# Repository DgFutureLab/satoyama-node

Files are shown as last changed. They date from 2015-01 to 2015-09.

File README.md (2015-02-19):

satoyama-node
=============

Satoyama Sensor Network node stack. This stack is designed to connect chibis and sabotens to <a href="https://github.com/DgFutureLab/satoyama-api">Satoyama API</a>. Created by <a href="http://fljapan.com/">Future Lab</a> based on <a href="http://www.freaklabsstore.com">Freaklabs open hardware</a>.

# Prerequisites

## Hardware
(List of provided parts: board, sensors, batteries, etc.)

(NOTE: Add mark on saboten board to connect the FTDI Breakout board in the right direction!!)

## Software
1. Arduino IDE 1.0.6 (Does not work with Arduino 1.5.8 BETA). Get it <a href="http://www.arduino.cc/">here</a>
2. git

# Installation
Follow these steps to set up a Satoyama sensor node!
## Get the code
1. Download this repository: $ git clone https://github.com/DgFutureLab/satoyama-node.git
2. Go into the new directory: $ cd satoyama-node
3. Download all the libraries: $ git pull && git submodule init && git submodule update && git submodule status

## Prepare Arduino libraries

Import the required libraries into your Arduino IDE:  

1. satoyama-libs/SatoyamaChibiLib 
2. satoyama-libs/SdFat 
3. satoyama-libs/chibiArduino-master
4. satoyama-libs/PCF2127
5. satoyama-libs/Humidity_Temperature_Sensor
6. satoyama-libs/NewPing

If you use the standard Arduino GUI, go to Sketch → Import Library → Add Library and select each library name folder.

For the Saboten board: 

1. Copy the folder 'mighty-1284p-freaklabs' inside satoyama-libs to a folder called 'hardware' off your sketches directory, e.g. /Users/maniacbug/Source/Arduino/hardware/mighty-1284p
In a Mac environment: Arduino.app/contents/resources/Java/hardware/
2. Restart the IDE
3. Select Tools > Board > Freaklabs Saboten...

## Prepare the hardware

1. Attach a sonnar, a temperature sensor and a humidity sensor. The pin numbers are specified in <a href="https://github.com/DgFutureLab/satoyama-node/blob/master/SatoyamaChibiLib/config.h">this file</a> (6 for sonar, 0 for temp/humidity)
2. Connect the board to the computer
 
-In case of the Saboten:
Check that the FTDI Breakout board switch is on 5V

3. For OSX users, download the FTDI drivers from http://www.ftdichip.com/Drivers/VCP.htm

4. Open test_saboten/test_saboten.ino (for saboten)
4. Open File>Examples>Chibiarduino-master>4.cmdline (for Chibi)
5. Select your board on the dropdown menu Tool>Board>(FreakLabs Saboten for the saboten) or (Arduino Pro or ProMini (3.3V, 8MHz) w/ATmega328)
6. Upload it to the board
7. Open Arduino IDE's Serial Monitor
8. Set the communication to Carriage return and 57600 baud
9. Set the short address of this collector node by hand writing   *setsaddr* \<address\>  in the serial monitor command prompt. The address should be in HEXADECIMAL. (The address is currently (as of Jan, 2015) set via the script in satoyama-konohana) 
9. Upload collector/collector.ino into your Saboten board. (Include all the necessary libs from third-party-libs folder)

## Setup build system with CMake
Before we wrote the sketches using the Arduino GUI, but now we use standard CMake to generate make files.

1. Install CMake (e.g. brew install cmake on OSX)
2. Change directory into the folder containing the source code that you want to run on the board.
3. mkdir build (all the build files will be stored in this directory)
4. Navigate to build directory: cd build 
5. compile source code and upload to the device: cmake .. -Wno-dev && make && make upload (make sure that the build directory is empty, as CMake will complain otherwise)
6. Use screen to monitor output from the serial device (e.g. tty.usbserial-A501K9HW): /dev/tty.usbserial-A501K9HW 57600,sc8

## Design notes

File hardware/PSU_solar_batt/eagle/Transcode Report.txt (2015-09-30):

   ---- Transcoding 'E:\Jobs\Temp files\sonar\Voltage Regulator\Regulator\Regulator.GBL' ----   Mon Aug 31 23:26:08 2015

D10   --> D100
D11   --> D101
-----------------------------------------------------------------

   ---- Transcoding 'E:\Jobs\Temp files\sonar\Voltage Regulator\Regulator\Regulator.GBS' ----   Mon Aug 31 23:26:08 2015

D11   --> D102
-----------------------------------------------------------------

   ---- Transcoding 'E:\Jobs\Temp files\sonar\Voltage Regulator\Regulator\Regulator.GTL' ----   Mon Aug 31 23:26:08 2015

D10   --> D103
D11   --> D104
D12   --> D105
D13   --> D106
D14   --> D107
D15   --> D108
D16   --> D109
-----------------------------------------------------------------

   ---- Transcoding 'E:\Jobs\Temp files\sonar\Voltage Regulator\Regulator\Regulator.GTO' ----   Mon Aug 31 23:26:08 2015

D10   --> D110
D11   --> D111
D12   --> D112
D13   --> D113
D14   --> D114
-----------------------------------------------------------------

   ---- Transcoding 'E:\Jobs\Temp files\sonar\Regulator\MCP Regulator\Regulator\Regulator.GBS' ----   Sat Sep 19 06:32:56 2015

D10   --> D100
D11   --> D101
D12   --> D102
D13   --> D103
-----------------------------------------------------------------

   ---- Transcoding 'E:\Jobs\Temp files\sonar\Regulator\MCP Regulator\Regulator\Regulator.GTL' ----   Sat Sep 19 06:32:56 2015

D10   --> D104
D11   --> D105
D12   --> D106
D13   --> D107
D14   --> D108
D15   --> D109
-----------------------------------------------------------------

   ---- Transcoding 'E:\Jobs\Temp files\sonar\Regulator\MCP Regulator\Regulator\Regulator.GTO' ----   Sat Sep 19 06:32:56 2015

D10   --> D110
D11   --> D111
D12   --> D112
D13   --> D113
D14   --> D114
D15   --> D115
D16   --> D116
-----------------------------------------------------------------

   ---- Transcoding 'E:\Jobs\Temp files\sonar\Regulator\MCP Regulator\Regulator\Regulator.GTS' ----   Sat Sep 19 06:32:56 2015

D10   --> D117
D11   --> D118
D12   --> D119
D13   --> D120
D14   --> D121
D15   --> D122
D16   --> D123
D17   --> D124
D18   --> D125
-----------------------------------------------------------------

   ---- Transcoding 'E:\Jobs\Temp files\sonar\Regulator\MCP Regulator\BackUp\Regulator\Regulator.GBS' ----   Sat Sep 26 23:08:06 2015

D10   --> D100
D11   --> D101
D13   --> D102
D14   --> D103
D15   --> D104
D16   --> D105
D17   --> D106
D18   --> D107
D19   --> D108
D20   --> D109
-----------------------------------------------------------------

   ---- Transcoding 'E:\Jobs\Temp files\sonar\Regulator\MCP Regulator\BackUp\Regulator\Regulator.GTL' ----   Sat Sep 26 23:08:06 2015

D10   --> D110
D11   --> D111
D12   --> D112
D13   --> D113
D14   --> D114
D15   --> D115
D16   --> D116
D17   --> D117
D18   --> D118
D19   --> D119
D20   --> D120
D21   --> D121
D22   --> D122
D23   --> D123
D24   --> D124
-----------------------------------------------------------------

   ---- Transcoding 'E:\Jobs\Temp files\sonar\Regulator\MCP Regulator\BackUp\Regulator\Regulator.GTO' ----   Sat Sep 26 23:08:06 2015

D10   --> D125
D11   --> D126
D12   --> D127
D13   --> D128
D14   --> D129
D15   --> D130
D17   --> D131
D18   --> D132
D20   --> D133
-----------------------------------------------------------------

   ---- Transcoding 'E:\Jobs\Temp files\sonar\Regulator\MCP Regulator\BackUp\Regulator\Regulator.GTS' ----   Sat Sep 26 23:08:06 2015

D10   --> D134
D11   --> D135
D12   --> D136
D13   --> D137
D14   --> D138
D15   --> D139
D16   --> D140
D17   --> D141
D18   --> D142
D19   --> D143
D20   --> D144
D21   --> D145
D22   --> D146
D23   --> D147
D24   --> D148
D25   --> D149
D26   --> D150
D27   --> D151
D28   --> D152
-----------------------------------------------------------------

   ---- Transcoding 'E:\Jobs\Temp files\sonar\Regulator\MCP Regulator\BackUp\Regulator\Regulator.GBS' ----   Sat Sep 26 23:10:48 2015

D10   --> D153
D11   --> D154
D13   --> D155
D14   --> D156
D15   --> D157
D16   --> D158
D17   --> D159
D18   --> D160
D19   --> D161
D20   --> D162
-----------------------------------------------------------------

   ---- Transcoding 'E:\Jobs\Temp files\sonar\Regulator\MCP Regulator\BackUp\Regulator\Regulator.GTL' ----   Sat Sep 26 23:10:48 2015

D10   --> D163
D11   --> D164
D12   --> D165
D13   --> D166
D14   --> D167
D15   --> D168
D16   --> D169
D17   --> D170
D18   --> D171
D19   --> D172
D20   --> D173
D21   --> D174
D22   --> D175
D23   --> D176
D24   --> D177
-----------------------------------------------------------------

   ---- Transcoding 'E:\Jobs\Temp files\sonar\Regulator\MCP Regulator\BackUp\Regulator\Regulator.GTO' ----   Sat Sep 26 23:10:48 2015

D10   --> D178
D11   --> D179
D12   --> D180
D13   --> D181
D14   --> D182
D15   --> D183
D17   --> D184
D18   --> D185
D20   --> D186
-----------------------------------------------------------------

   ---- Transcoding 'E:\Jobs\Temp files\sonar\Regulator\MCP Regulator\BackUp\Regulator\Regulator.GTS' ----   Sat Sep 26 23:10:48 2015

D10   --> D187
D11   --> D188
D12   --> D189
D13   --> D190
D14   --> D191
D15   --> D192
D16   --> D193
D17   --> D194
D18   --> D195
D19   --> D196
D20   --> D197
D21   --> D198
D22   --> D199
D23   --> D200
D24   --> D201
D25   --> D202
D26   --> D203
D27   --> D204
D28   --> D205
-----------------------------------------------------------------

   ---- Transcoding 'E:\Jobs\Temp files\sonar\Regulator\MCP Regulator\BackUp\Regulator\Regulator.GBS' ----   Sat Sep 26 23:12:03 2015

D10   --> D100
D11   --> D101
D13   --> D102
D14   --> D103
D15   --> D104
D16   --> D105
D17   --> D106
D18   --> D107
D19   --> D108
D20   --> D109
-----------------------------------------------------------------

   ---- Transcoding 'E:\Jobs\Temp files\sonar\Regulator\MCP Regulator\BackUp\Regulator\Regulator.GTL' ----   Sat Sep 26 23:12:03 2015

D10   --> D110
D11   --> D111
D12   --> D112
D13   --> D113
D14   --> D114
D15   --> D115
D16   --> D116
D17   --> D117
D18   --> D118
D19   --> D119
D20   --> D120
D21   --> D121
D22   --> D122
D23   --> D123
D24   --> D124
-----------------------------------------------------------------

   ---- Transcoding 'E:\Jobs\Temp files\sonar\Regulator\MCP Regulator\BackUp\Regulator\Regulator.GTO' ----   Sat Sep 26 23:12:03 2015

D10   --> D125
D11   --> D126
D12   --> D127
D13   --> D128
D14   --> D129
D15   --> D130
D17   --> D131
D18   --> D132
D20   --> D133
-----------------------------------------------------------------

   ---- Transcoding 'E:\Jobs\Temp files\sonar\Regulator\MCP Regulator\BackUp\Regulator\Regulator.GTS' ----   Sat Sep 26 23:12:03 2015

D10   --> D134
D11   --> D135
D12   --> D136
D13   --> D137
D14   --> D138
D15   --> D139
D16   --> D140
D17   --> D141
D18   --> D142
D19   --> D143
D20   --> D144
D21   --> D145
D22   --> D146
D23   --> D147
D24   --> D148
D25   --> D149
D26   --> D150
D27   --> D151
D28   --> D152
-----------------------------------------------------------------

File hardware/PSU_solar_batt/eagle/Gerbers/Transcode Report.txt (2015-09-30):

   ---- Transcoding 'E:\Jobs\Temp files\sonar\Regulator\MCP Regulator\Regulator\Gerbers\Regulator.GBS' ----   Mon Sep 21 23:30:57 2015

D10   --> D100
D11   --> D101
D13   --> D102
D14   --> D103
D15   --> D104
-----------------------------------------------------------------

   ---- Transcoding 'E:\Jobs\Temp files\sonar\Regulator\MCP Regulator\Regulator\Gerbers\Regulator.GTL' ----   Mon Sep 21 23:30:57 2015

D10   --> D105
D11   --> D106
D12   --> D107
D13   --> D108
D14   --> D109
D15   --> D110
D16   --> D111
D17   --> D112
D18   --> D113
-----------------------------------------------------------------

   ---- Transcoding 'E:\Jobs\Temp files\sonar\Regulator\MCP Regulator\Regulator\Gerbers\Regulator.GTO' ----   Mon Sep 21 23:30:57 2015

D10   --> D114
D11   --> D115
D12   --> D116
D13   --> D117
D14   --> D118
D15   --> D119
D16   --> D120
-----------------------------------------------------------------

   ---- Transcoding 'E:\Jobs\Temp files\sonar\Regulator\MCP Regulator\Regulator\Gerbers\Regulator.GTS' ----   Mon Sep 21 23:30:57 2015

D10   --> D121
D11   --> D122
D12   --> D123
D13   --> D124
D14   --> D125
D15   --> D126
D16   --> D127
D17   --> D128
D18   --> D129
D19   --> D130
D20   --> D131
-----------------------------------------------------------------

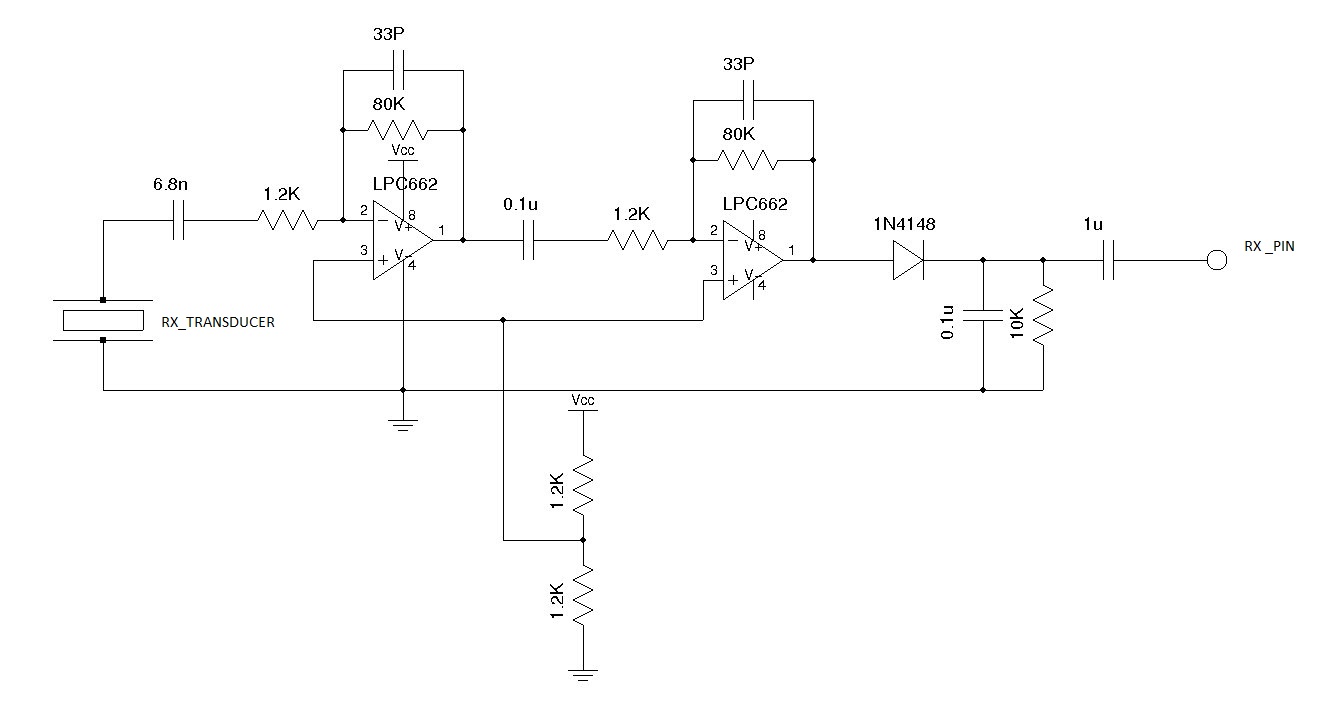
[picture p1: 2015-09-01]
hardware/range_finder/design2/hbridge/RX.jpg

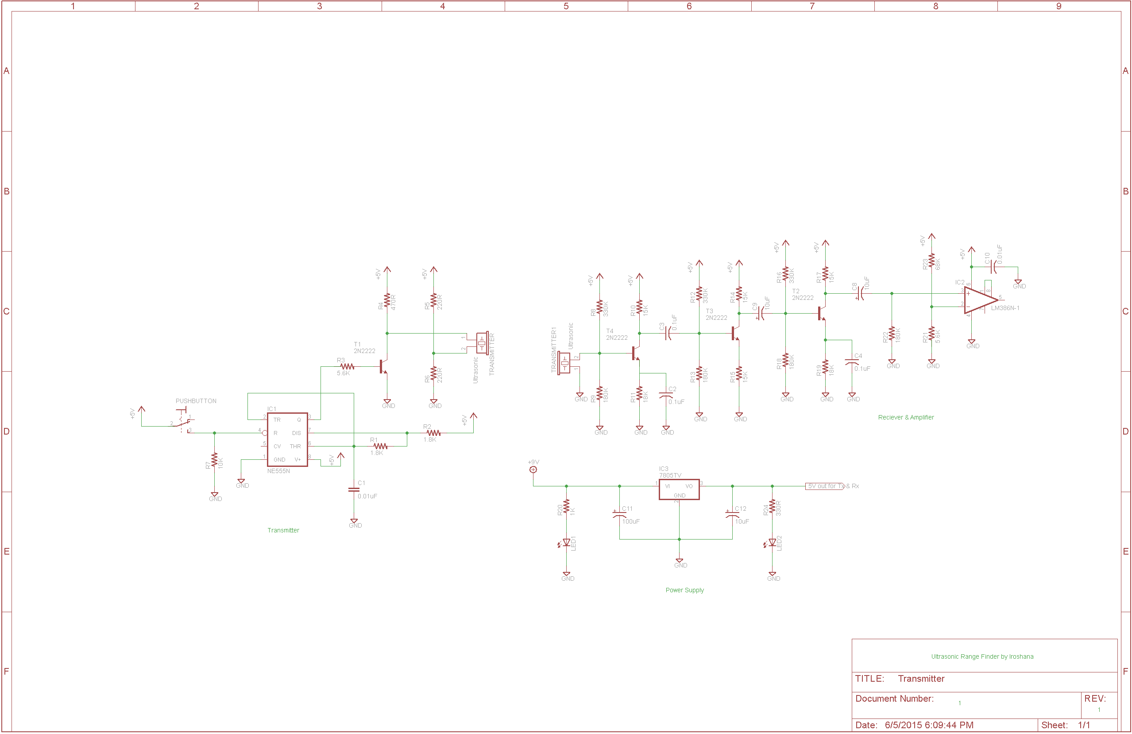
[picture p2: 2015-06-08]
hardware/range_finder/design1/Schematics/Schematics.png

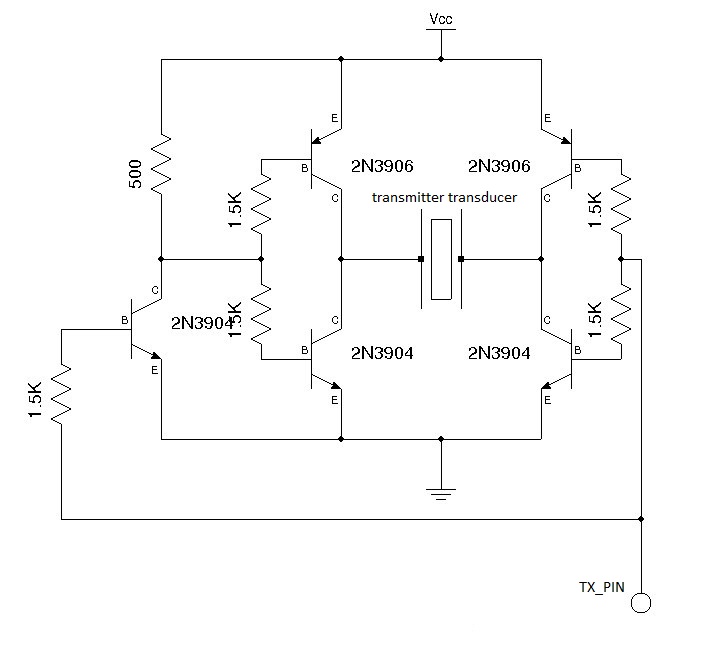
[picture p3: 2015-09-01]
hardware/range_finder/design2/hbridge/TX.jpg

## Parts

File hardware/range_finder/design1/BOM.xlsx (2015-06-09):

 | Bill Of Materials - Ultrasonic Range Finder
Part |  | Qty
Ics
555 |  | 1
LM386 |  | 1
Transistors
2N2222 |  | 4
Resistors(0.25W)
220ohm |  | 2
330ohm |  | 1
470ohm |  | 1
1K |  | 1
1.8K |  | 1
5.6K |  | 2
15K |  | 4
18K |  | 2
68K |  | 1
180K |  | 4
330K |  | 3
Capacitors
10uF(25V, Electrolytic) |  | 3
0.1uF(Ceramic) |  | 5
0.01uF (Ceramic) |  | 2
LM7805 |  | 1
Pin 8 IC Base |  | 2
LED Red |  | 1
LED Green |  | 1
1N4007 Diode |  | 1

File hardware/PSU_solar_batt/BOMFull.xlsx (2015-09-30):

Part |  | Qty | Schematic Ref. No: | Store Part No: | Manu: No: | Store
MCP1642B/D | REGULATOR IC | 1 | IC1 | 579-MCP1642D-18I/MS (http://www.mouser.com/ProductDetail/Microchip-Technology/MCP1642D-18I-MS/) | MCP1642D-18I/MS (http://www.mouser.com/ProductDetail/Microchip-Technology/MCP1642D-18I-MS/) | Mouser
MCP1642D-ADJ | REGULATOR IC | 1 | IC2 | MCP1642B-ADJI/MS-ND | MCP1642B-ADJI/MS | Digikey
10uF(16V) | CAPACITOR(ELECTROLYTIC) | 4 | C1-C4 | 565-4265-1-ND | EMLE160ADA100MD73G | Digikey
4.7uH | INDUCTOR | 2 | L1,L2 | 732-3333-1-ND (http://www.digikey.com/product-detail/en/74437324047/732-3333-1-ND/2791031) | 74437324047 (http://www.digikey.com/product-detail/en/74437324047/732-3333-1-ND/2791031) | Digikey
1MOHM | RESISTOR(0.25W) | 1 | R4 | 311-1.0MERCT-ND (http://www.digikey.com/product-detail/en/RC1206JR-071ML/311-1.0MERCT-ND/732134) | RC1206JR-071ML (http://www.digikey.com/product-detail/en/RC1206JR-071ML/311-1.0MERCT-ND/732134) | Digikey
820KOHM | RESISTOR(0.25W) | 1 | R6 | 311-820KFRCT-ND (http://www.digikey.com/product-detail/en/RC1206FR-07820KL/311-820KFRCT-ND/732081) | RC1206FR-07820KL (http://www.digikey.com/product-detail/en/RC1206FR-07820KL/311-820KFRCT-ND/732081) | Digikey
150KOHM | RESISTOR(0.25W) | 3 | R1-R3 | 311-150KERCT-ND (http://www.digikey.com/product-detail/en/RC1206JR-07150KL/311-150KERCT-ND/732171) | RC1206JR-07150KL (http://www.digikey.com/product-detail/en/RC1206JR-07150KL/311-150KERCT-ND/732171) | Digikey
2WAY DIP SWITCH |  | 1 | REGULATORS | CT2092MS-ND (http://www.digikey.com/product-detail/en/209-2MS/CT2092MS-ND/217658) | 209-2MS (http://www.digikey.com/product-detail/en/209-2MS/CT2092MS-ND/217658) | Digikey
3PIN MALE HEADER |  | 1 | SV1 | 3M9448-ND (http://www.digikey.com/product-detail/en/961103-6404-AR/3M9448-ND/2071489) | 961103-6404-AR (http://www.digikey.com/product-detail/en/961103-6404-AR/3M9448-ND/2071489) | Digikey
JST-XH |  | 1 | BATIN | A33893-ND (http://www.digikey.com/product-detail/en/5-103669-1/A33893-ND/1000909) | 5-103669-1 (http://www.digikey.com/product-detail/en/5-103669-1/A33893-ND/1000909) | Digikey
2PIN CONNECTOR |  | 3 | SOLARINPUT,3.3VOUT,5VOUT | ED1975-ND | EDZ500/2DS | Digikey

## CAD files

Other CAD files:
enclosure/protector.3dm

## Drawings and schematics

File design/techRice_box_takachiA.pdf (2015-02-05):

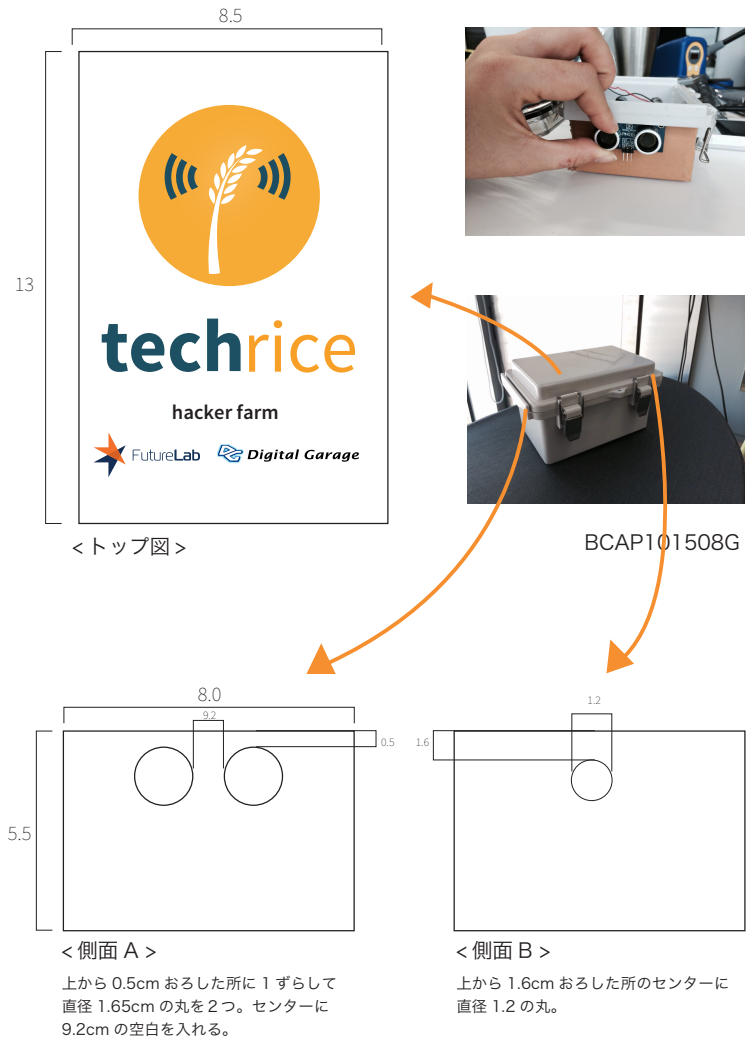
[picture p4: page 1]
上から 1.6cm おろした所のセンターに 直径 1.2 の丸。; hacker farm; rice; < トップ図 >; BCAP101508G

上から 0.5cm おろした所に 1 ずらして
直径 1.65cm の丸を２つ。センターに
9.2cm の空白を入れる。

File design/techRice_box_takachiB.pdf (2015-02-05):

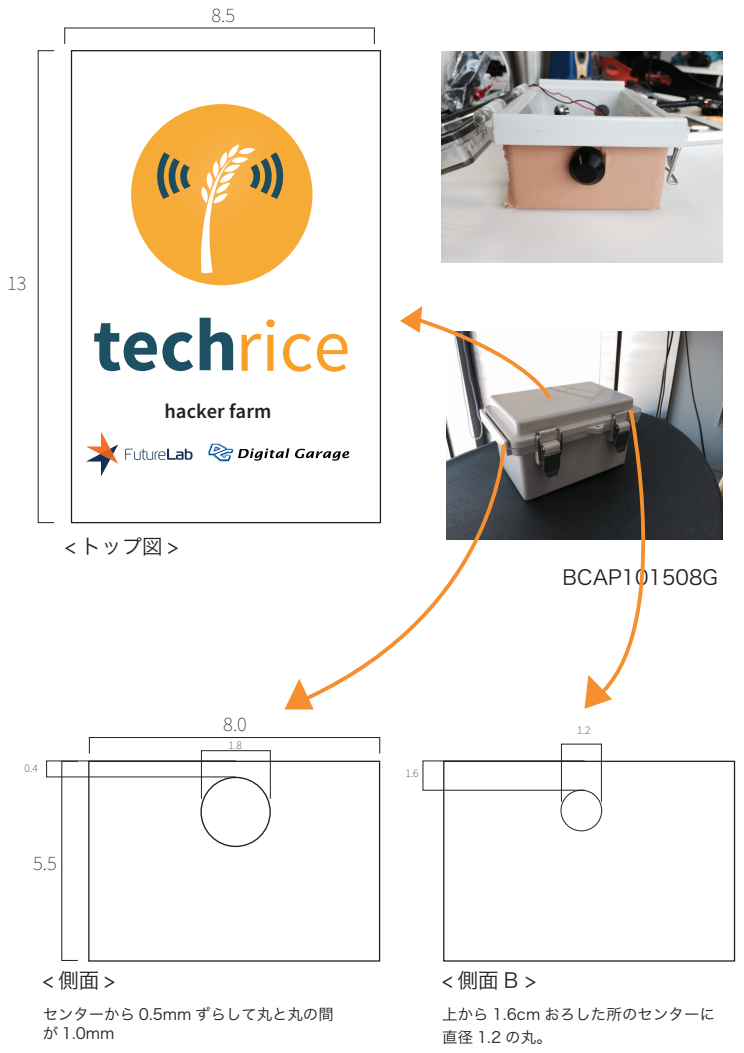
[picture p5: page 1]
BCAP101508G; 上から 1.6cm おろした所のセンターに 直径 1.2 の丸。; hacker farm; rice; < トップ図 >; センターから 0.5mm ずらして丸と丸の間 が 1.0mm

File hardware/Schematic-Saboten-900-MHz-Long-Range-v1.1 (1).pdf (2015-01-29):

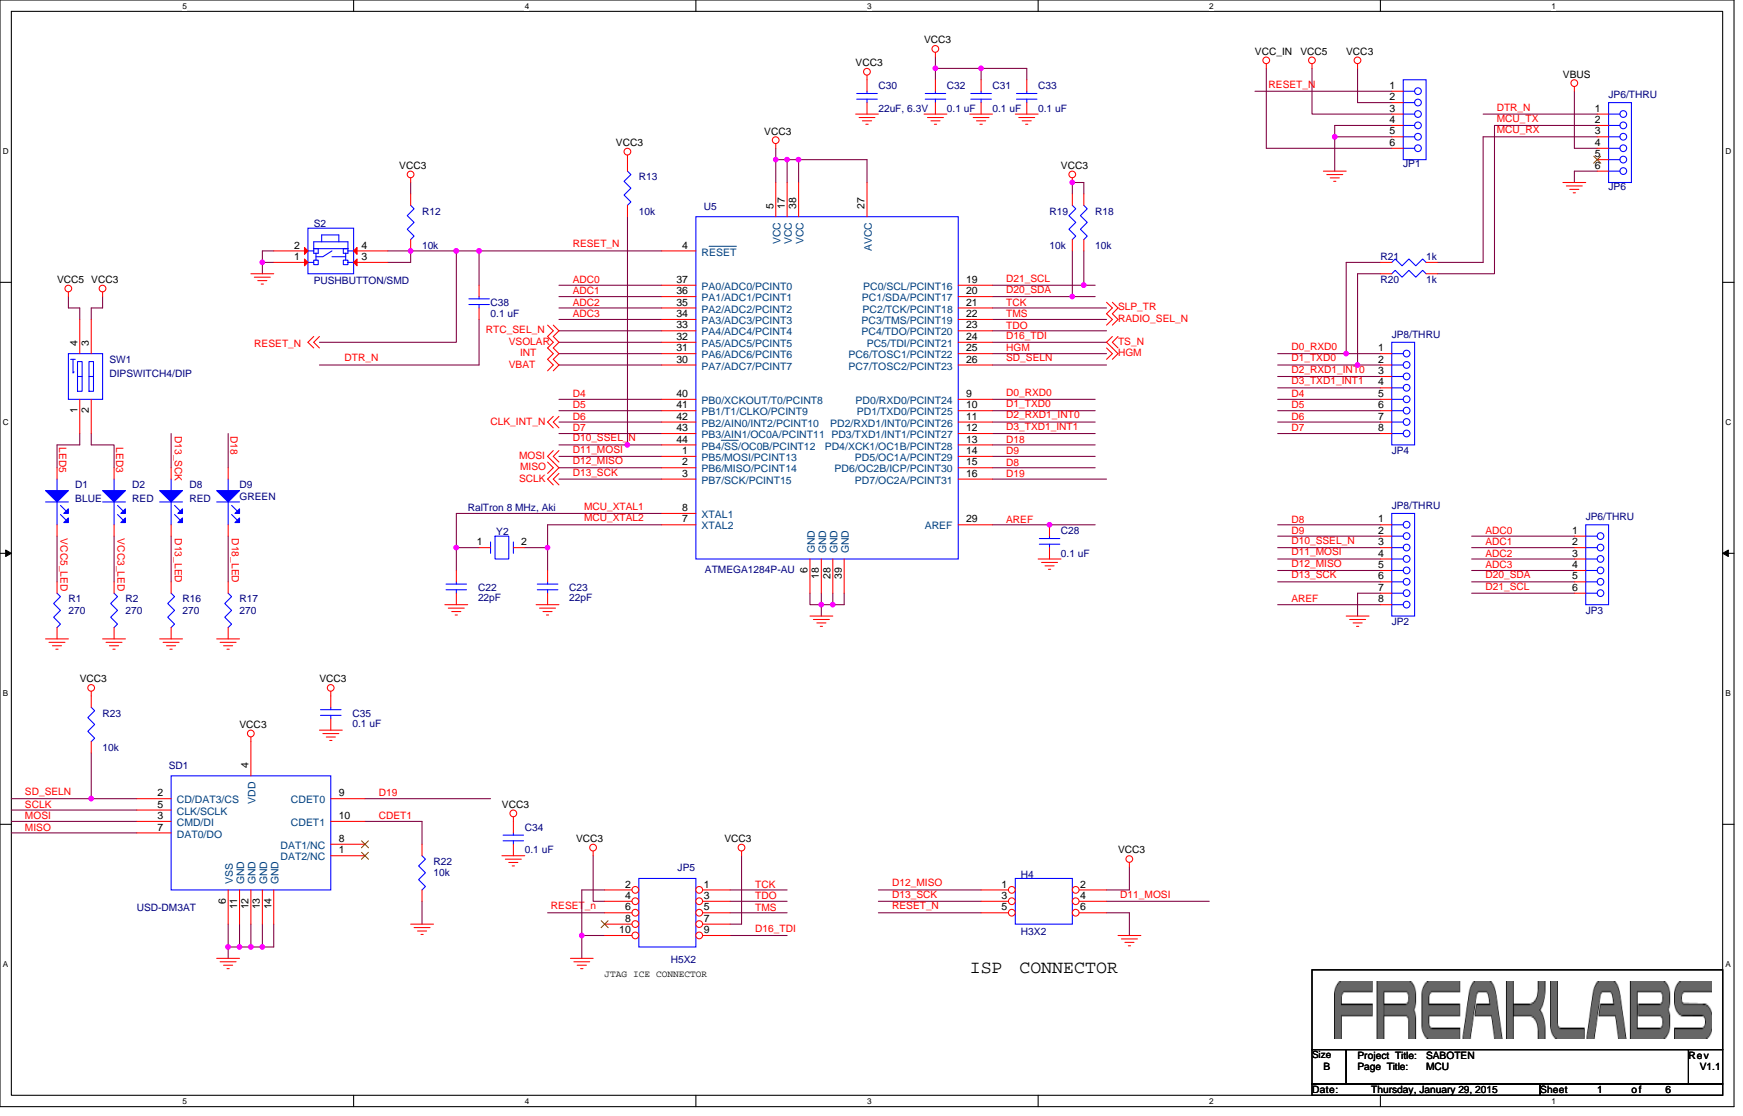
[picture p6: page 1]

Size Size Size B B B | Project Title: Project Title: Project Title: SABOTEN SABOTEN SABOTEN Page Title: Page Title: Page Title: MCU MCU MCU | Rev Rev Rev V1.1 V1.1 V1.1

Date: Date: Date: Thursday, January 29, 2015 Thursday, January 29, 2015 Thursday, January 29, 2015 | Sheet Sheet Sheet 1 1 1 of of of 6 6 6

D | D

H3

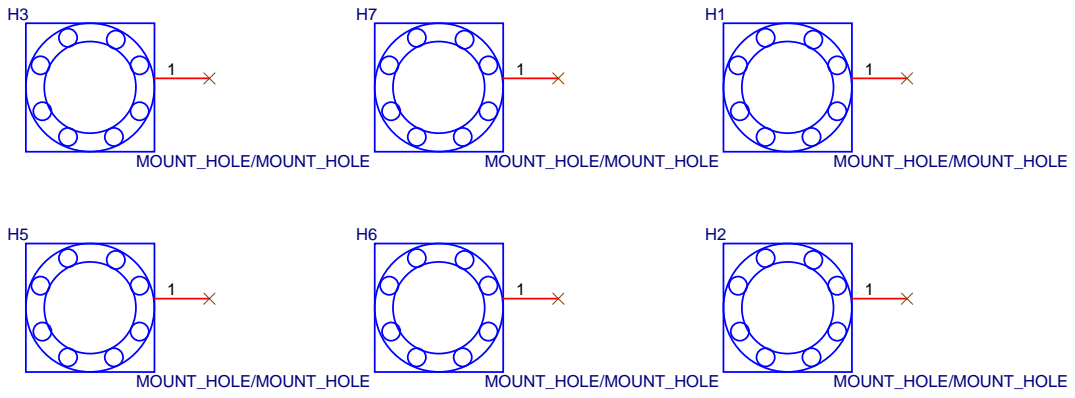
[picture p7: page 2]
MOUNT_HOLE/MOUNT_HOLE

Size Size Size A A A | Project Title: Project Title: Project Title: SABOTEN SABOTEN SABOTEN Page Title: Page Title: Page Title: MISC MISC MISC | Rev Rev Rev V1.1 V1.1 V1.1

Date: Date: Date: Thursday, January 29, 2015 Thursday, January 29, 2015 Thursday, January 29, 2015 | Sheet Sheet Sheet 2 2 2 of of of 6 6 6

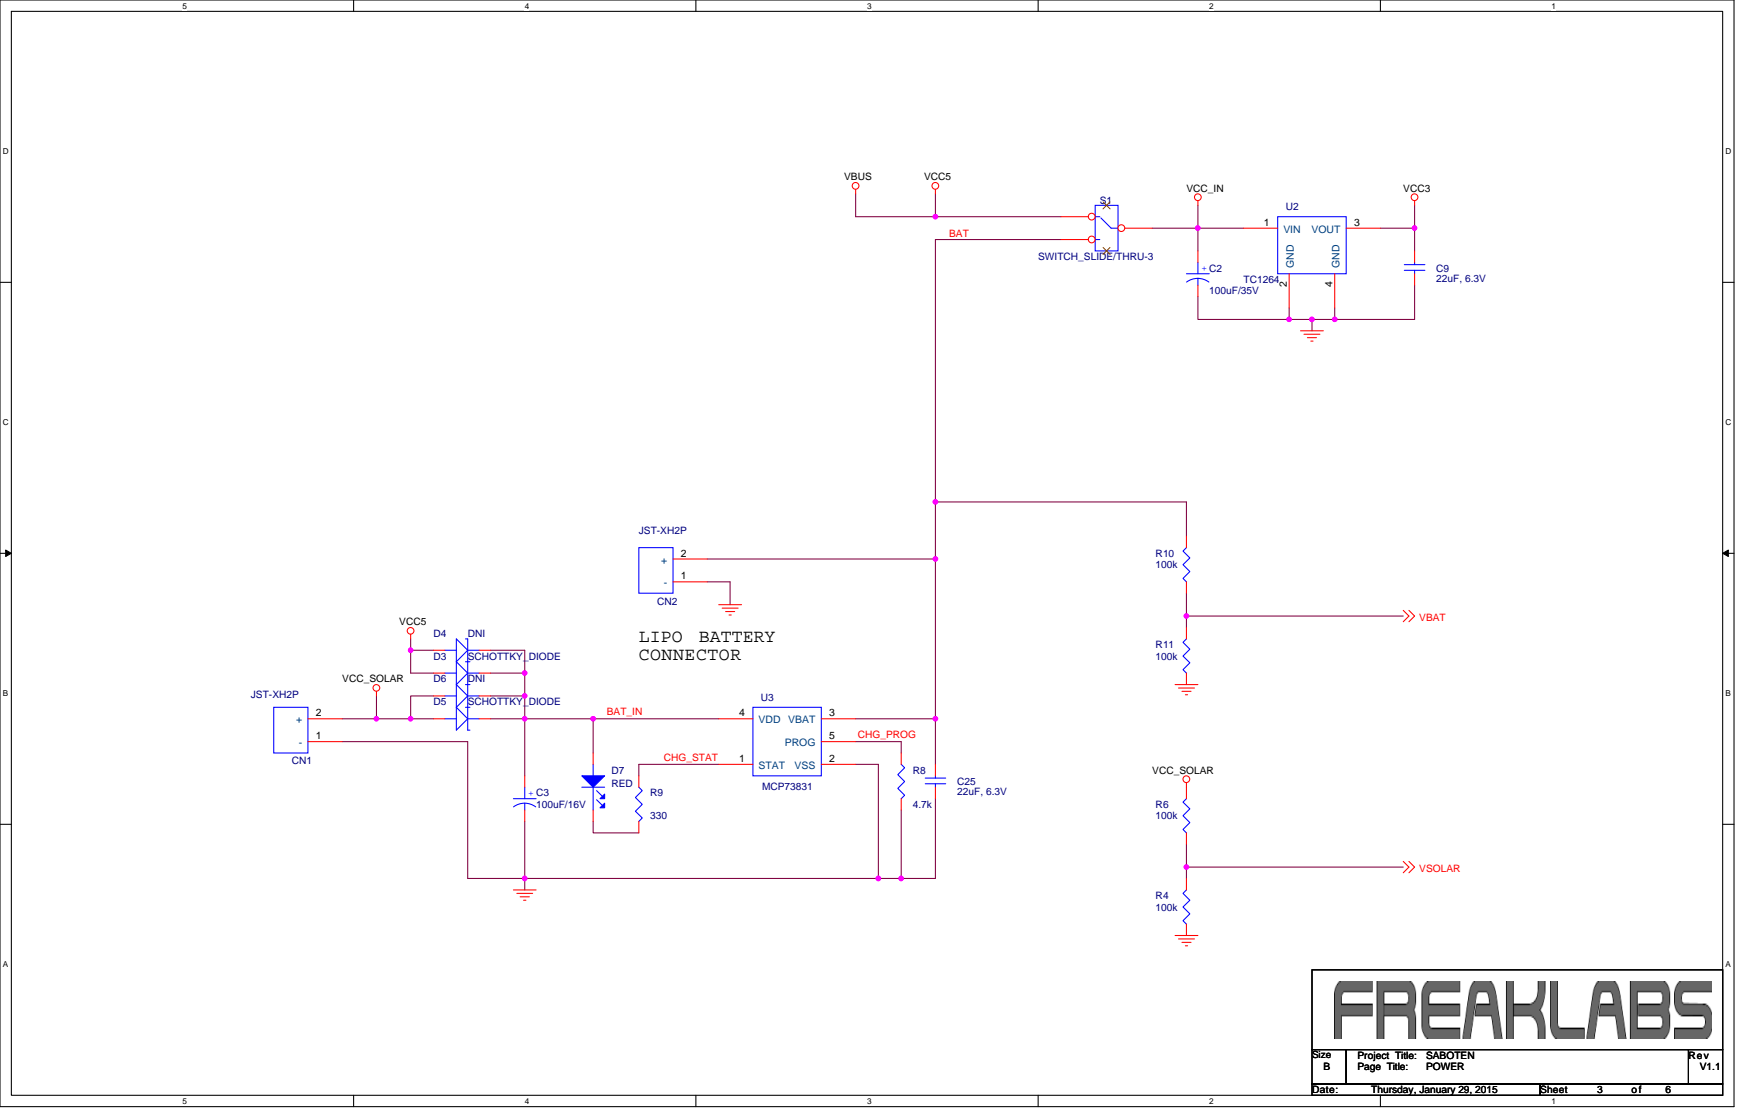
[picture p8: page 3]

Size Size Size B B B | Project Title: Project Title: Project Title: SABOTEN SABOTEN SABOTEN Page Title: Page Title: Page Title: POWER POWER POWER | Rev Rev Rev V1.1 V1.1 V1.1

Date: Date: Date: Thursday, January 29, 2015 Thursday, January 29, 2015 Thursday, January 29, 2015 | Sheet Sheet Sheet 3 3 3 of of of 6 6 6

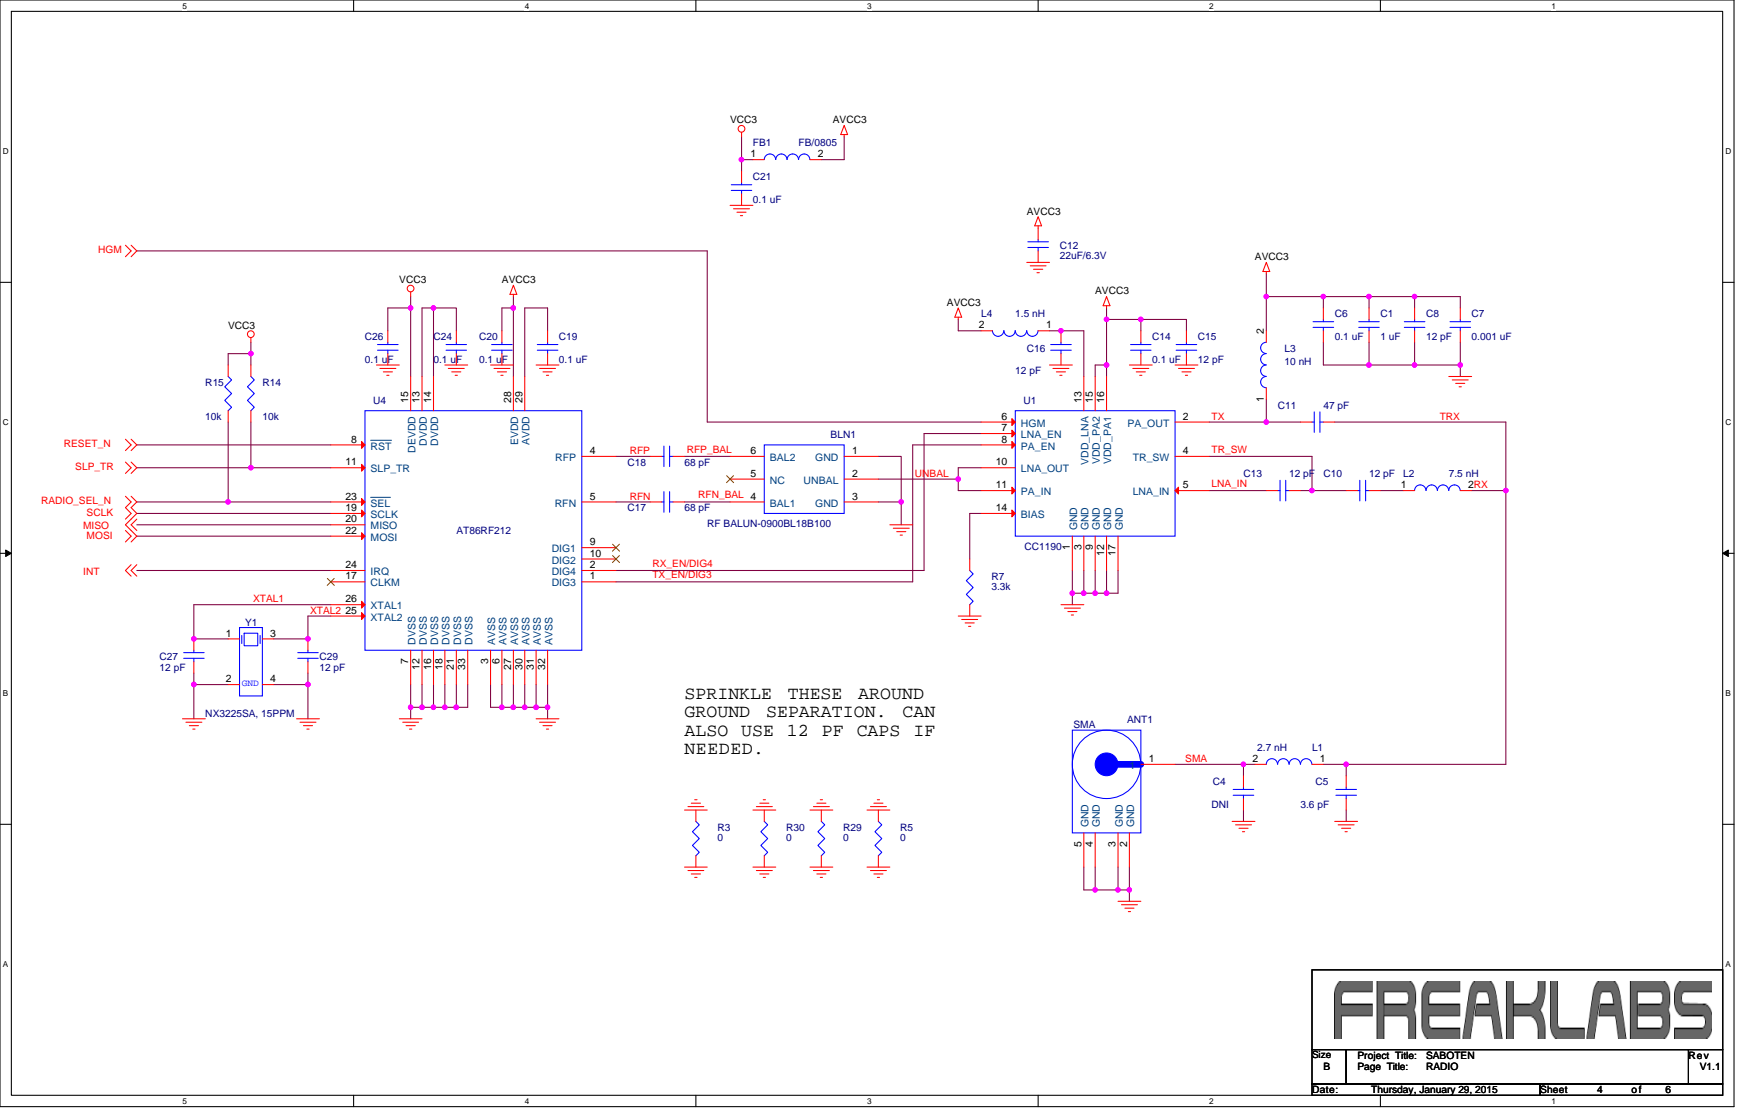
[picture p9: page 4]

SPRINKLE THESE AROUND
GROUND SEPARATION. CAN
ALSO USE 12 PF CAPS IF
NEEDED.

Size Size Size B B B | Project Title: Project Title: Project Title: SABOTEN SABOTEN SABOTEN Page Title: Page Title: Page Title: RADIO RADIO RADIO | Rev Rev Rev V1.1 V1.1 V1.1

Date: Date: Date: Thursday, January 29, 2015 Thursday, January 29, 2015 Thursday, January 29, 2015 | Sheet Sheet Sheet 4 4 4 of of of 6 6 6

D | D
VCC3 | VCC3

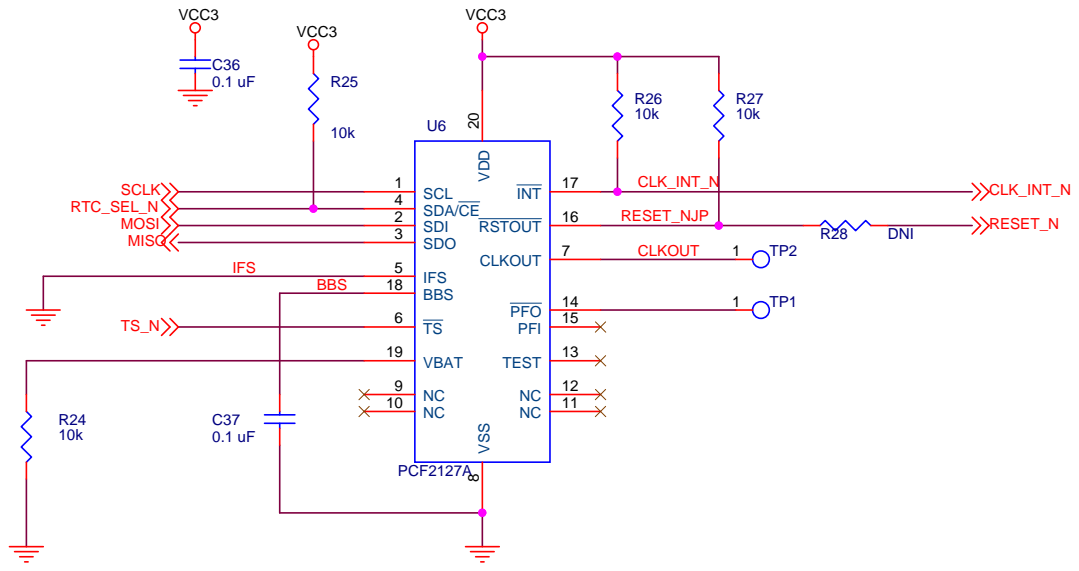
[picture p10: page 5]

Size Size Size A A A | Project Title: Project Title: Project Title: SABOTEN SABOTEN SABOTEN Page Title: Page Title: Page Title: RTC RTC RTC | Rev Rev Rev V1.1 V1.1 V1.1

Date: Date: Date: Thursday, January 29, 2015 Thursday, January 29, 2015 Thursday, January 29, 2015 | Sheet Sheet Sheet 5 5 5 of of of 6 6 6

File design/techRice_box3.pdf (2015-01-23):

## BCAP101508G

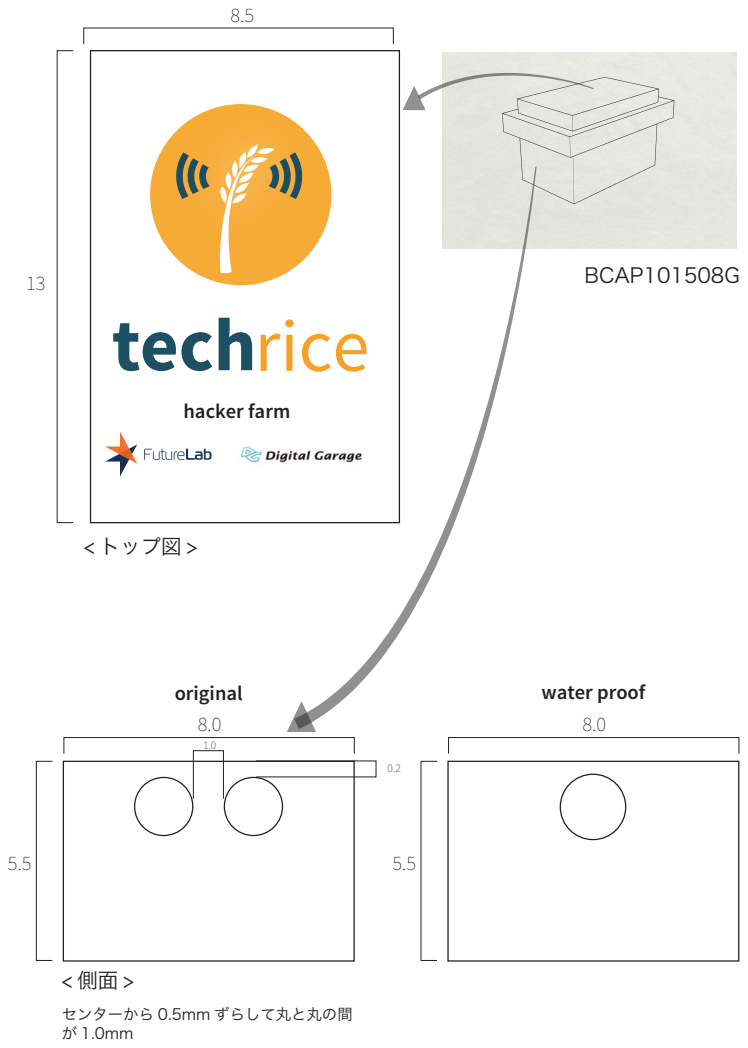
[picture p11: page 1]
original; water proof; hacker farm; rice; < トップ図 >; センターから 0.5mm ずらして丸と丸の間 が 1.0mm

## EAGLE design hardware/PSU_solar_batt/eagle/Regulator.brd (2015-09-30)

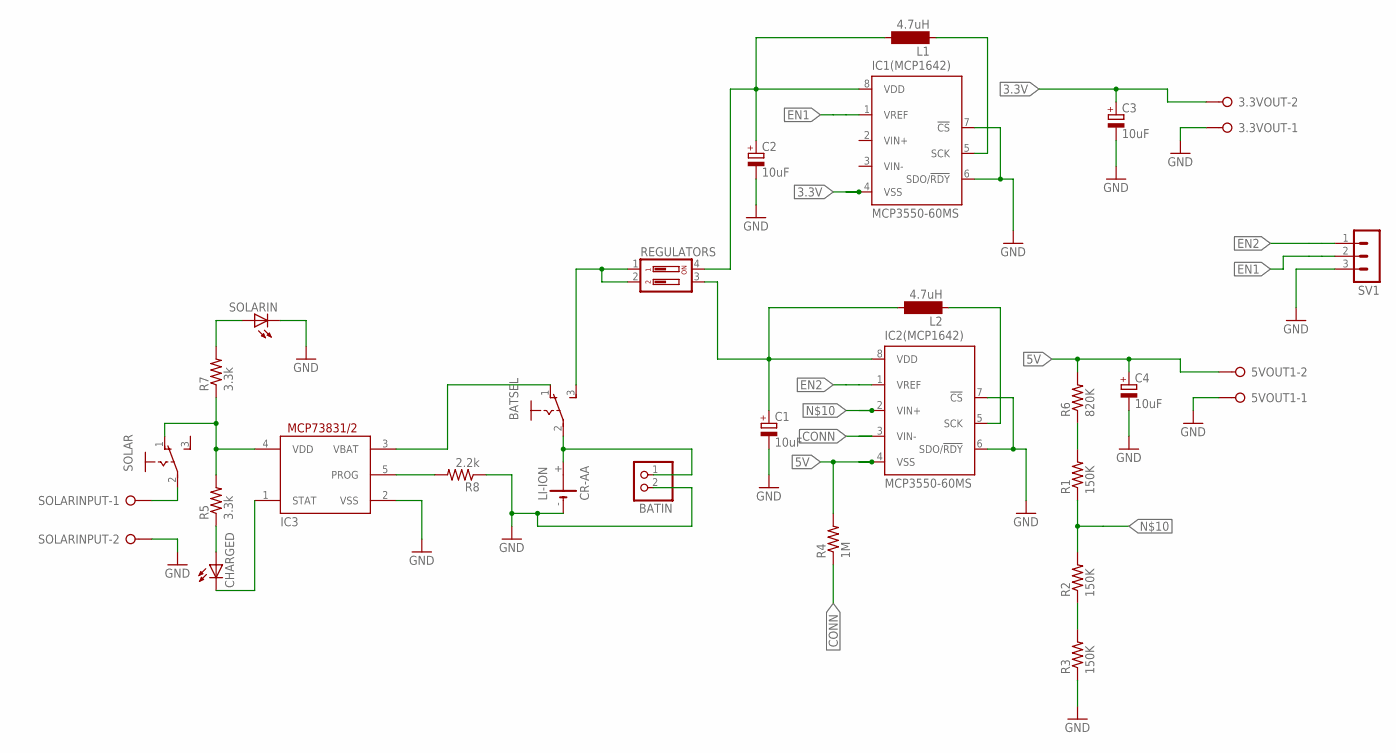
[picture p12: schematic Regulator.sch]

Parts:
3.3VOUT, 5VOUT1: W237-02P; W237-132
BATIN: JST_2PIN-THM; JST-PH-2-THM
BATSEL: 255SB
C1, C2, C3, C4: 10uF; 140CLH-1010
CHARGED: LEDCHIP-LED0603; CHIP-LED0603
IC1(MCP1642), IC2(MCP1642): MCP3550-60MS; MSOP8
IC3: MCP73831/OT; SOT23-5L
L1, L2: 4.7uH; MS85
LI-ION: CR-AA; CRAA
R1, R2, R3: 150K; M0805
R4: 1M; M0805
R5, R7: 3.3k; M3216
R6: 820K; M0805
R8: 2.2k; M3216
REGULATORS: DIP02YL
SOLAR: 255SB
SOLARIN: LEDCHIP-LED0603; CHIP-LED0603
SOLARINPUT: W237-02P; W237-132
SV1: MA03-1

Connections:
3.3V: 3.3VOUT.2, C3.+, IC1(MCP1642).4 (VSS)
5V: 5VOUT1.2, C4.+, IC2(MCP1642).4 (VSS), R4.2, R6.2
CONN: IC2(MCP1642).3 (VIN-), R4.1
EN1: IC1(MCP1642).1 (VREF), SV1.2
EN2: IC2(MCP1642).1 (VREF), SV1.1
MCP1642: C2.+, IC1(MCP1642).8 (VDD), L1.2, REGULATORS.4
unnamed: IC1(MCP1642).5 (SCK), L1.1
unnamed: R1.2, R6.1
unnamed: IC2(MCP1642).5 (SCK), L2.1
unnamed: R2.1, R3.2
unnamed: C1.+, IC2(MCP1642).8 (VDD), L2.2, REGULATORS.3
unnamed: IC3.4 (VDD), R5.2, R7.1, SOLAR.1 (O)
unnamed: IC2(MCP1642).2 (VIN+), R1.1, R2.2
unnamed: CHARGED.A, R5.1
unnamed: CHARGED.C, IC3.1 (STAT)
unnamed: BATSEL.3 (S), REGULATORS.1, REGULATORS.2
unnamed: R7.2, SOLARIN.A
unnamed: IC3.5 (PROG), R8.2
unnamed: BATSEL.1 (O), IC3.3 (VBAT)
unnamed: 3.3VOUT.1, 5VOUT1.1, BATIN.2 (1), C1.-, C2.-, C3.-, C4.-, IC1(MCP1642).6 (SDO/!RDY), IC1(MCP1642).7 (!CS), IC2(MCP1642).6 (SDO/!RDY), IC2(MCP1642).7 (!CS), IC3.2 (VSS), LI-ION.-, R3.1, R8.1, SOLARIN.C, SOLARINPUT.2, SV1.3
unnamed: SOLAR.2, SOLARINPUT.1
unnamed: BATIN.1 (2), BATSEL.2, LI-ION.+

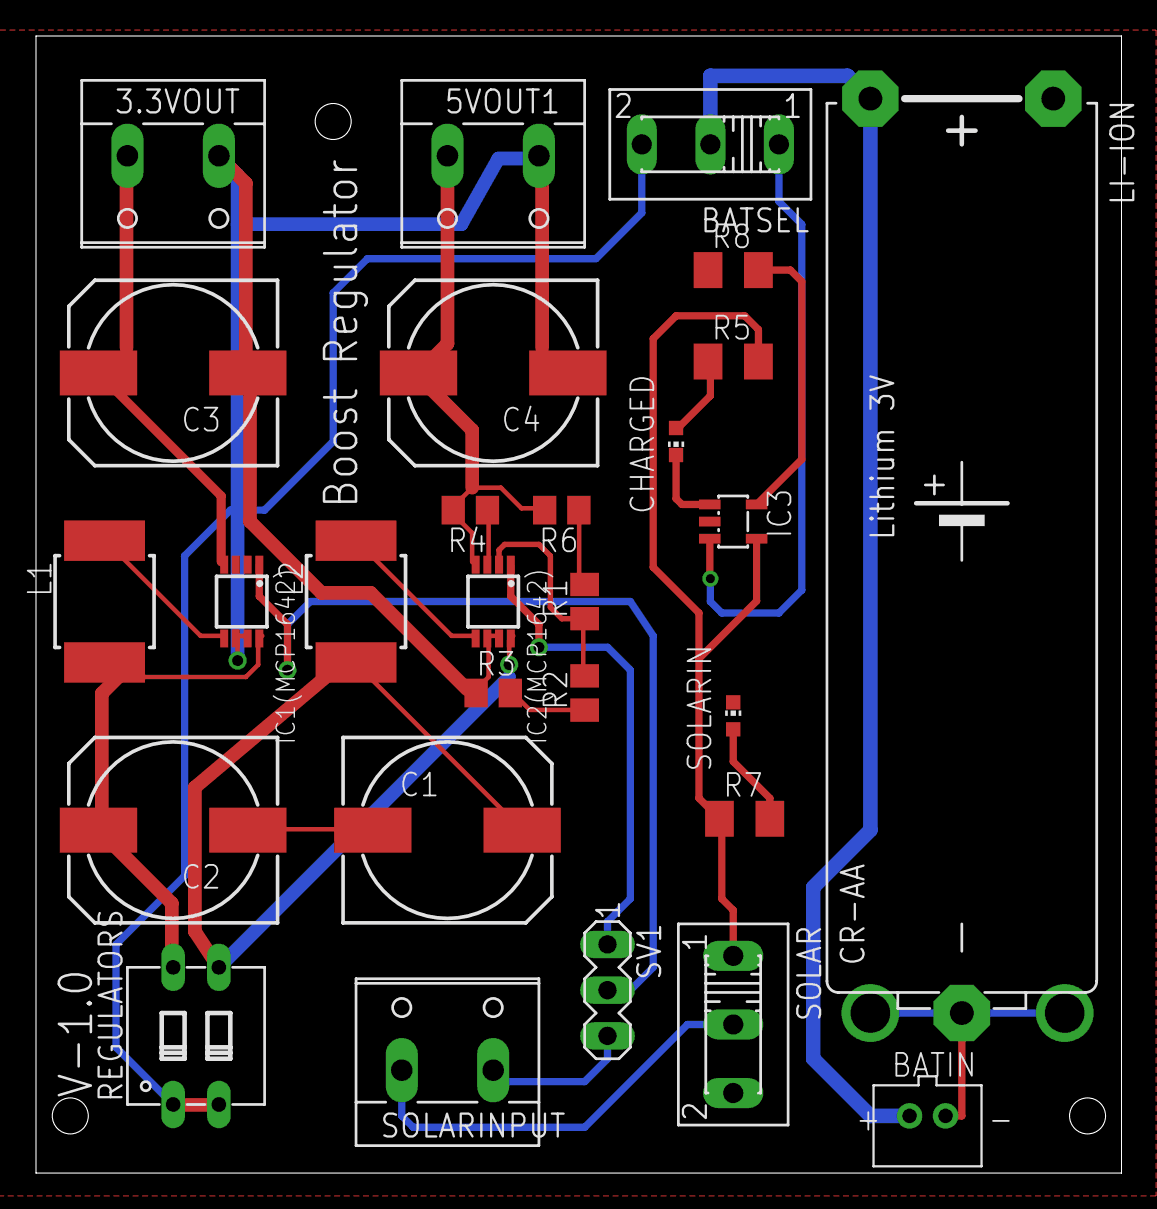
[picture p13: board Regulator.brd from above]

Board: 2 copper layers, 60.3 x 63.2 mm, 28 parts (0 on the bottom side), 22 nets.

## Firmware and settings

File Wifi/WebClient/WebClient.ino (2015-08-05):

#include <ArduinoJson.h>

/*************************************************** 
  This is an example for the Adafruit CC3000 Wifi Breakout & Shield

  Designed specifically to work with the Adafruit WiFi products:
  ----> https://www.adafruit.com/products/1469

  Adafruit invests time and resources providing this open source code, 
  please support Adafruit and open-source hardware by purchasing 
  products from Adafruit!

  Written by Limor Fried & Kevin Townsend for Adafruit Industries.  
  BSD license, all text above must be included in any redistribution
 ****************************************************/
 
 /*
This example does a test of the TCP client capability:
  * Initialization
  * Optional: SSID scan
  * AP connection
  * DHCP printout
  * DNS lookup
  * Optional: Ping
  * Connect to website and print out webpage contents
  * Disconnect
SmartConfig is still beta and kind of works but is not fully vetted!
It might not work on all networks!
*/
#include <Adafruit_CC3000.h>
#include <ccspi.h>
#include <SPI.h>
#include <string.h>
#include "utility/debug.h"

// These are the interrupt and control pins
#define ADAFRUIT_CC3000_IRQ   3  // MUST be an interrupt pin!
// These can be any two pins
#define ADAFRUIT_CC3000_VBAT  5
#define ADAFRUIT_CC3000_CS    10
// Use hardware SPI for the remaining pins
// On an UNO, SCK = 13, MISO = 12, and MOSI = 11
Adafruit_CC3000 cc3000 = Adafruit_CC3000(ADAFRUIT_CC3000_CS, ADAFRUIT_CC3000_IRQ, ADAFRUIT_CC3000_VBAT,
                                         SPI_CLOCK_DIVIDER); // you can change this clock speed

//#define WLAN_SSID       "HWD15_F49FF3ED0D6D"           // cannot be longer than 32 characters!
//#define WLAN_PASS       "10ii3ybg21f8317"
//#define WLAN_SSID       "FutureLab"           // cannot be longer than 32 characters!
//#define WLAN_PASS       "tacobeya11"
#define WLAN_SSID       "AirPort25512"           // cannot be longer than 32 characters!
#define WLAN_PASS       "1739818891249"
// Security can be WLAN_SEC_UNSEC, WLAN_SEC_WEP, WLAN_SEC_WPA or WLAN_SEC_WPA2
#define WLAN_SECURITY   WLAN_SEC_WPA2

#define IDLE_TIMEOUT_MS  3000      // Amount of time to wait (in milliseconds) with no data 
                                   // received before closing the connection.  If you know the server
                                   // you're accessing is quick to respond, you can reduce this value.

// What page to grab!
//#define WEBSITE      "google.com"
//#define WEBPAGE      "/"

#define WEBSITE      "satoyamacloud.com"
#define WEBPAGE      "/reading"



/**************************************************************************/
/*!
    @brief  Sets up the HW and the CC3000 module (called automatically
            on startup)
*/
/**************************************************************************/

uint32_t ip;

void setup(void)
{
  Serial.begin(115200);
  Serial.println(F("Hello, CC3000!\n")); 

  Serial.print("Free RAM: "); Serial.println(getFreeRam(), DEC);
  
  /* Initialise the module */
  Serial.println(F("\nInitializing..."));
  if (!cc3000.begin())
  {
    Serial.println(F("Couldn't begin()! Check your wiring?"));
    while(1);
  }
  
  // Optional SSID scan
  // listSSIDResults();
  
  Serial.print(F("\nAttempting to connect to ")); Serial.println(WLAN_SSID);
  if (!cc3000.connectToAP(WLAN_SSID, WLAN_PASS, WLAN_SECURITY)) {
    Serial.println(F("Failed!"));
    while(1);
  }
   
  Serial.println(F("Connected!"));
  
  /* Wait for DHCP to complete */
  Serial.println(F("Request DHCP"));
  while (!cc3000.checkDHCP())
  {
    delay(100); // ToDo: Insert a DHCP timeout!
  }  

  /* Display the IP address DNS, Gateway, etc. */  
  while (! displayConnectionDetails()) {
    delay(1000);
  }

//  ip = 2160562973;
  ip = 0;
  // Try looking up the website's IP address
  Serial.print(WEBSITE); Serial.print(F(" -> "));
  while (ip == 0) {
    if (! cc3000.getHostByName(WEBSITE, &ip)) {
      Serial.println(F("Couldn't resolve!"));
    }
    delay(500);
  }
  cc3000.printIPdotsRev(ip);
//  Serial.println("RESOLVED: ");
//  Serial.println(ip);
  // Optional: Do a ping test on the website
  /*
  Serial.print(F("\n\rPinging ")); cc3000.printIPdotsRev(ip); Serial.print("...");  
  replies = cc3000.ping(ip, 5);
  Serial.print(replies); Serial.println(F(" replies"));
  */  

  /* Try connecting to the website.
     Note: HTTP/1.1 protocol is used to keep the server from closing the connection before all data is read.
  */
//  Serial.print("Starting web client");
  
    DynamicJsonBuffer jsonBuffer;
    JsonArray& root = jsonBuffer.createArray();
    for(int i = 0; i<2; i++){
      JsonObject& reading = root.createNestedObject();
      reading["sensor_id"] = i;
      reading["value"].set(5.534, 3);
      reading["timestamp"] = "2015-8-5 10:46";
//      int s = reading.size();
  //  int s = root.size();
//      Serial.println("ASDASD");
//      int total_size = 2 + 14 + sizeof(reading["sensor_id"]) + 11 + sizeof(reading["value"]) + 15 + sizeof(reading["timestamp"]);
//      Serial.println(sizeof(reading["timestamp"]));
    }

  int data_length = root.printTo(Serial) + 5; 
  char buf[10];
  Serial.println("Data length");
  Serial.println(buf);
  itoa(data_length, buf, 10);
  Adafruit_CC3000_Client www = cc3000.connectTCP(ip, 80);
  
  if (www.connected()) {
//      www.fastrprint(F("POST /reading HTTP/1.1\r\nHost: satoyamacloud.com\r\nContent-Length: 21\r\nAccept: */*\r\nConnection: keep-alive\r\nContent-Type: application/x-www-form-urlencoded\r\n\r\nsensor_id=2&value=28"));
      www.fastrprint(F("POST /readings HTTP/1.1\r\nHost: satoyamacloud.com\r\nContent-Length: "));
      www.fastrprint(buf);
      www.fastrprint(F("\r\nAccept: */*\r\nConnection: close\r\nContent-Type: application/x-www-form-urlencoded\r\n\r\ndata="));
      root.printTo(www);  
      www.println();
  } else {
    Serial.println(F("Connection failed"));    
    return;
  }

Serial.println(F("-------------------------------------"));

/* Read data until either the connection is closed, or the idle timeout is reached. */ 
unsigned long lastRead = millis();
while (www.connected() && (millis() - lastRead < IDLE_TIMEOUT_MS)) {
  while (www.available()) {
    char c = www.read();
    Serial.print(c);
    lastRead = millis();
  }
}
www.close();
Serial.println(F("-------------------------------------"));

/* You need to make sure to clean up after yourself or the CC3000 can freak out */
/* the next time your try to connect ... */
Serial.println(F("\n\nDisconnecting"));
cc3000.disconnect();
  
}

void loop(void)
{
 delay(1000);
}

/**************************************************************************/
/*!
    @brief  Begins an SSID scan and prints out all the visible networks
*/
/**************************************************************************/

void listSSIDResults(void)
{
  uint32_t index;
  uint8_t valid, rssi, sec;
  char ssidname[33]; 

  if (!cc3000.startSSIDscan(&index)) {
    Serial.println(F("SSID scan failed!"));
    return;
  }

  Serial.print(F("Networks found: ")); Serial.println(index);
  Serial.println(F("================================================"));

  while (index) {
    index--;

    valid = cc3000.getNextSSID(&rssi, &sec, ssidname);
    
    Serial.print(F("SSID Name    : ")); Serial.print(ssidname);
    Serial.println();
    Serial.print(F("RSSI         : "));
    Serial.println(rssi);
    Serial.print(F("Security Mode: "));
    Serial.println(sec);
    Serial.println();
  }
  Serial.println(F("================================================"));

  cc3000.stopSSIDscan();
}

/**************************************************************************/
/*!
    @brief  Tries to read the IP address and other connection details
*/
/**************************************************************************/
bool displayConnectionDetails(void)
{
  uint32_t ipAddress, netmask, gateway, dhcpserv, dnsserv;
  
  if(!cc3000.getIPAddress(&ipAddress, &netmask, &gateway, &dhcpserv, &dnsserv))
  {
    Serial.println(F("Unable to retrieve the IP Address!\r\n"));
    return false;
  }
  else
  {
    Serial.print(F("\nIP Addr: ")); cc3000.printIPdotsRev(ipAddress);
    Serial.print(F("\nNetmask: ")); cc3000.printIPdotsRev(netmask);
    Serial.print(F("\nGateway: ")); cc3000.printIPdotsRev(gateway);
    Serial.print(F("\nDHCPsrv: ")); cc3000.printIPdotsRev(dhcpserv);
    Serial.print(F("\nDNSserv: ")); cc3000.printIPdotsRev(dnsserv);
    Serial.println();
    return true;
  }
}

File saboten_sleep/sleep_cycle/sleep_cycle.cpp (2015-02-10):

/*
Collects data from different sensors and sends it to 
 the aggregator as defined in "config.h"
 */

#include "sleep_cycle.h"
#include <chibi.h>

// satoyama-chibi-lib includes
// Defines pin numbers for sensors and also a simple format to send
// information to the satoyama edge router
#include <satoyama_config.h>
#include <utilsawesome.h>

// Saboten includes
#include <avr/sleep.h>
#include <avr/power.h>
#include <avr/wdt.h>
#include <Wire.h>
#include <SPI.h>
#include <SdFat.h>
#include <pcf2127.h>


int hgmPin = 14;
int sdCsPin = 15;
int rtcCsPin = 28; 
int ledPin = 18;
int sdDetectPin = 19;
int vbatPin = 31;
int vsolPin = 29;

uint8_t temp;
PCF2127 pcf(0, 0, 0, rtcCsPin, &temp);

/**************************************************************************/
// Initialize
/**************************************************************************/
//int interruptPin = 6;

void setup()
{
  // Initialize the chibi command line and set the speed to 57600 bps
  
  chibiCmdInit(57600);

  // set up rtc chip select
  pinMode(rtcCsPin, OUTPUT);
  digitalWrite(rtcCsPin, HIGH);

  pinMode(sdCsPin, INPUT);
  digitalWrite(sdCsPin, HIGH);

  pinMode(sdDetectPin, INPUT);
  digitalWrite(sdDetectPin, LOW);

//  testSecondInterrupt();
//  pinMode(interruptPin, INPUT);
//
  // pcf.enableSecondInterrupt();
  // pcf.setInterruptToPulse();

  attachInterrupt(2, rtcInterrupt, FALLING);
}

/**************************************************************************/
// Loop
/**************************************************************************/
void loop()
{

//  delay(1000);
//  byte msf = pcf.read(PCF_CONTROL_2);
//  Serial.print("MSF: ");
//  Serial.println(msf, BIN);
//  delay(1000);
  sleepMCU();
//  testSecondInterrupt();
}

/*
void testSecondInterrupt(){
  enableSecondInterrupt();
  setInterruptToPulse();
}
*/

void rtcInterrupt(){
  detachInterrupt(2);
}

void sleepMCU()
{
  attachInterrupt(2, rtcInterrupt, FALLING);
  Serial.println("Sleeping MCU");
  delay(100);

  // set pullups on inputs
  

  // write sleep mode
//  sei() //   sleep enable interrupt
  set_sleep_mode(SLEEP_MODE_PWR_DOWN);
  sleepRadio(true);
  sleep_enable();        // setting up for sleep ...
  
  ADCSRA &= ~(1 << ADEN);    // Disable ADC
  sleep_mode();

  sleep_disable();
//  sleepRadio(false);
//  pinMode(sdCsPin, INPUT);
//  digitalWrite(sdCsPin, LOW);
//
//  pinMode(sdDetectPin, INPUT);
//  digitalWrite(sdDetectPin, HIGH);

  doStuff();
  

}

void doStuff(){
  
  Serial.println("I'm awake!");
  for(int i = 5; i > 0; i--){
    Serial.print("Going to sleep in ");
    Serial.println(i);
    delay(100);
  }
  
  
}

void sleepRadio(bool val)
{
  
  if (val)
  {
    digitalWrite(hgmPin, LOW);
  
    // set up chibi regs to turn off external P/A
    chibiRegWrite(0x4, 0x20);
  }
  else
  {
    digitalWrite(hgmPin, HIGH);
    
    // set up chibi regs to turn on external P/A
    chibiRegWrite(0x4, 0xA0);
  }
  
  // turn on/off radio
  chibiSleepRadio(val);
}
//
//


// void enableSecondInterrupt(){
//   byte RC1 = pcf.read(PCF_CONTROL_1);
//   setControlBit(&RC1, BIT_MI, 0); // disable minute interrupt
//   setControlBit(&RC1, BIT_SI, 1); // enable second interrupt
//   pcf.write(PCF_CONTROL_1, RC1);
// }  

// void enableMinuteInterrupt(){
//   byte RC1 = pcf.read(PCF_CONTROL_1);
//   setControlBit(&RC1, BIT_MI, 1); // enable minute interrupt
//   setControlBit(&RC1, BIT_SI, 0); // disable second interrupt
//   pcf.write(PCF_CONTROL_1, RC1);
// }  


// void setInterruptToPulse(){
//   byte reg_10h = pcf.read(PCF_WATCHDOG_TIM_CTL);
//   reg_10h |= B00100000;
//   pcf.write(PCF_WATCHDOG_TIM_CTL, reg_10h);
// }

// void setInterruptToPermanent(){
//   byte reg_10h = pcf.read(PCF_WATCHDOG_TIM_CTL);
//   reg_10h &= B11011111;
//   pcf.write(PCF_WATCHDOG_TIM_CTL, reg_10h);
// }


// byte setControlBit(byte *controlByte, byte registerBit, boolean value){
//   /*

//   */
//   *controlByte |= (value<<registerBit);
// }

// void readTimerRegisters(){
//   char buffer [100];
//   uint8_t hour_set, minute_set, second_set;
//   pcf.alarmReadTime(&hour_set, &minute_set, &second_set);
//   sprintf(buffer, "ALARM TIME IN REGISTERS: hour: %u, minute: %u, second: %u", hour_set, minute_set, second_set);
//   Serial.println((char*) buffer);
// }

// void printTime(){
//   char buffer [100];
//   uint8_t hour_set, minute_set, second_set;
//   pcf.readTime(&hour_set, &minute_set, &second_set);
//   sprintf(buffer, "TIME NOW: hour: %u, minute: %u, second: %u", hour_set, minute_set, second_set);
//   Serial.println((char*) buffer); 
// }


// void setWakeupTime(){
//   uint8_t hour, minute, second;


//   pcf.readTime(&hour, &minute, &second);
//   char time_buffer [100];
//   sprintf (time_buffer, "CURRENT TIME: %u-%u-%u", hour, minute, second);
//   Serial.println((char*) time_buffer);

//   second = (second + 5) % 60;
//   char wakeuptime_buffer [100];
//   sprintf (wakeuptime_buffer, "ALARM TIME TO WRITE: %u-%u-%u", hour, minute, second);
//   Serial.println((char*) wakeuptime_buffer);


//   pcf.alarmWriteTime(hour, minute, second);
//   pcf.readModWriteBit(PCF_CONTROL_2, BIT_AIE, 1);    

// }

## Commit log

2014-12-03 Arduino library code added
2014-12-05 Moving library
    [pins.ods]
2014-12-16 Adds set short address function in collector sketch
    [collector.ino, test_saboten.ino]
2014-12-16 deleted third party libs folder
    [pins.ods]
2015-01-07 Adds pin definitions for VBAT and VSOL
2015-01-08 Sensor node now sends battery voltage as well
2015-01-27 Testing second interrupt
2015-01-27 Second interrupt works!
2015-01-27 Interrupt works!! Arduino get it!
2015-01-29 Adds saboten schematic v1.1
2015-02-04 Inserts pointer for debugging purposes
2015-02-05 Adding all the power management functions to the collector code
2015-02-19 Includes temp and sonar libs
2015-02-19 Adds sensor reading to power managed code
2015-02-19 BOOM! Working ricefield sketch with power management.
2015-03-25 Fixes attachInterrupt in setup && deletes old code
    [ricefield.cpp]
2015-03-25 Adds function to read battery voltage
2015-03-26 Ricefield sketch is now using library function to read battery level
2015-03-31 moves board specific setup to board constructor
2015-03-31 Initializes board as pointer
2015-04-09 Fixed bug where file was not opened roperly at random times
    [ricefield.cpp]
2015-04-09 Ricefield sketch now stores battery voltage to SD card
2015-04-10 Switches to using Saboten function for reading diagnostics (such as voltage level)
2015-04-17 Added reading from the actual sensor, and changed to new post and get functions
2015-04-21 Saboten schematics
    [SABOTEN.GBL, SABOTEN.GBO, SABOTEN.GBS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]
2015-04-24 Ricefield program with sonar
2015-04-27 Checkout here to get code for self-contained sensor node
2015-05-14 Adds LTSpice simulation of basic negative feedback opamp circuit
2015-05-14 Adds simulation of opamp with bias voltage on positive input
2015-05-19 Adds old arduino version of ricefield sketch for Togas demo at Solid.
2015-05-19 Adds the 3d model of the sonar protector designed by Risa
    [protector.3dm]
2015-05-21 Adds snapshots of Daikis first idea for node enclosure
2015-06-08 Adds schematic for TX/RX ultrasonic range finder
    [Transmitter.sch]
2015-06-08 Adds simulation of TX circuit using pulse generator model
2015-06-08 Adds simulation of TX circuit using 555 to generate pulse train
2015-06-09 Renames schematics folder to hardware
    [Transmitter.sch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]
2015-06-09 Adds BOM for design1
    [BOM.xlsx]
2015-06-09 TX circuit now uses 2N2222 model instead of generic NPN model
2015-07-19 Adds schematic/simulation of circuitry to switch between TX and RX modes in the sonar
2015-07-19 Adds TX circuit based on H bridge configuration
2015-07-20 Adds LTSpice file with TX circuit and simulated RX signal, with a signal that switches transducer between TX and RX modes
2015-07-21 Adds active lowpass filter with cap to remove DC offset from signal
2015-07-21 Fixes faulty wiring of transistor for VCC enable
2015-07-22 Adds first stage amp with LPF, removes unused voltage sources and rearranges
2015-07-25 Adds graphs for water level and battery voltage during first deployment
2015-08-14 Adds sketch that slices array. Hopefully this code will be able to solve the Wifi shield crashing, which is probably due to buffer overflow
    [slice.ino]
2015-08-23 Fixes node_key str concat & misc
    [ricefield_arduino.ino]
2015-09-01 Adds single transducer rx/tx schematic
    [rxtx.sch]
2015-09-01 Adds schematic for hbridge design. Not used atm and not tested, but I keep it for reference.
2015-09-01 Adds sketch that uses a hardware timer to chirp sonar. This is currently not very useful since the call is blocking, but since it is intended for a single transducer design that might not matter much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
2015-09-07 Adds arduino code for range finder (still untested)
2015-09-23 Arduino ricefield collector now works properly with new version of utilsawesome (tested)
2015-09-28 Changes to using timer interrupts for measuring distance as this is non-blocking
2015-09-30 Adds mouser compatible BOM for PSU
    [BOMFull.xlsx]
2015-09-30 Adds schematic, board and gerbers
    [Regulator.brd, Regulator.sch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]
2015-09-30 renames IC1 and IC2 to MCP1642 to avoid confusion (currently MCP3550 part is used instead because MCP1642 is not in the Microchip library)
    [Regulator.brd, Regulator.sch]
